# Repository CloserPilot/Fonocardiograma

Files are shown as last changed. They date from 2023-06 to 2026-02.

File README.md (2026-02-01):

# 🫀 Fonocardiograma

Sistema completo para **registro, visualización y análisis de fonocardiogramas (PCG)** que combina hardware electrónico, firmware para microcontrolador y aplicación móvil Android.
---

## 📌 Descripción del proyecto

Este proyecto entrega todas las partes necesarias para **reconstruir el dispositivo de prueba del fonocardiograma**, integrando adquisición de señal, transmisión inalámbrica y visualización multiplataforma.

Incluye:

- **Hardware** — diseños electrónicos y PCB para captura de señales acústicas cardiacas.
- **Firmware** — programa embebido para microcontrolador que adquiere y transmite datos.
- **Software móvil** — aplicación Android para comunicación con el hardware, visualización y exposición de datos en red local.
- **Documentación** — manuales y lista de partes.

Cada componente está diseñado para ser **independiente, reutilizable y extensible**.

---

## 📁 Estructura del repositorio

### 📦 APK/
Archivo **.apk instalable** de la aplicación Android, permitiendo su uso sin necesidad de compilación.

---

### 🛠 Circuitos/
Diseños electrónicos desarrollados en **KiCAD**:
- Esquemático del sistema.
- Diseño de PCB y capas correspondientes.

---

### 📲 Codigo AndroidStudio/
Proyecto completo de la aplicación Android desarrollado en **Android Studio**:
- Código fuente en Java.
- Interfaz de visualización de la señal.
- Gestión de conexión Bluetooth y red local.

La aplicación permite:
- Visualizar el fonocardiograma en el dispositivo móvil.
- Exponer la señal mediante **red local (LAN)** para su visualización en cualquier navegador web dentro de la misma red.

---

### 🧠 Codigo Arduino/
Código fuente para el microcontrolador (**ATTiny85 / AVR / Arduino compatible**):
- Configuración de ADC y adquisición de señal.
- Manejo de buffers de datos.
- Comunicación serial hacia el módulo Bluetooth **HC-05**.
- Scripts auxiliares para pruebas y depuración.

Este firmware es responsable de **capturar la señal acústica cardiaca y transmitirla a la aplicación móvil**.

---

### 📄 Documentacion.pdf
Documento técnico que describe:
- Objetivo del proyecto.
- Funcionamiento general del sistema.
- Interconexión entre hardware, firmware y aplicación.

---

### 🧾 Manual de usuario.pdf
Guía práctica para:
- Montaje del hardware.
- Uso del sistema de adquisición.
- Funcionamiento de la aplicación Android.
- Descripción de los módulos que integran la app.

---

### 📊 Lista de partes y costos.xlsx
Listado de componentes con:
- Cantidades requeridas.
- Costos estimados.
- Referencias de proveedores.

Facilita la reproducción del dispositivo.

---

## 📌 Uso del sistema

1. **Montaje de hardware**  
   Ensambla el circuito utilizando los esquemáticos de `Circuitos/` y la lista de partes.

2. **Carga de firmware**  
   Programa el microcontrolador con el código de `Codigo Arduino/`.

3. **Aplicación Android**  
   - Instala la app desde `APK/` o compílala desde `Codigo AndroidStudio/`.
   - Conecta el dispositivo vía Bluetooth.

4. **Visualización**  
   - Visualiza el fonocardiograma directamente en el teléfono.
   - Activa el **modo LAN** para acceder a la señal desde cualquier navegador web dentro de la misma red local (PC, tablet u otro dispositivo).

---

## 🎯 Casos de uso

- Prácticas académicas de bioinstrumentación.
- Análisis y estudio de bioseñales acústicas.
- Prototipado de sistemas biomédicos.
- Demostraciones de integración hardware–software–red.

---

## 🧩 Consideraciones

Este sistema **no sustituye equipos médicos certificados**. Está destinado a fines educativos, experimentales y de prototipado.

---

## 📜 Licencia

Licencia de código abierto (ver archivo `LICENSE` para detalles).

---

## 🤝 Contribuciones

Se aceptan mejoras en:
- Firmware
- Diseño electrónico
- Aplicación Android
- Visualización y análisis de señal

Usa *issues* o *pull requests* para proponer cambios.





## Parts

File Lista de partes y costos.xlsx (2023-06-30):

 | Fono_V3A | Fono_VB | Fono_VC
Componente | Cantidad | Cantidad | Cantidad | Cantidad Total | Detalles | Lote (Pz) | Lotes necesitados | Precio de Lote (Mx) | Placa A,B,C a fabricar | Total (Mx) | Link
R200K | 2 | 2 | 1 | 5 | Resistencia 0805 | 100 | 1 | 11 | 20.0 | 11.00 | https://es.aliexpress.com/item/1005001794062302.html?curPageLogUid=m6kVDcOp25Kb
R100K | 5 | 6 | 3 | 14 | Resistencia 0805 | 100 | 1 | 11 | 7.1 | 11.00
R75K | 1 | 1 | 2 | 4 | Resistencia 0805 | 100 | 1 | 11 | 25.0 | 11.00
R51K | 2 | 2 | 2 | 6 | Resistencia 0805 | 100 | 1 | 11 | 16.7 | 11.00
R39K | 1 |  |  | 1 | Resistencia 0805 | 100 | 1 | 11 | 100.0 | 11.00
R15K | 1 | 1 | 1 | 3 | Resistencia 0805 | 100 | 1 | 11 | 33.3 | 11.00
R10K | 5 | 3 | 3 | 11 | Resistencia 0805 | 100 | 1 | 11 | 9.1 | 11.00
R6.8K | 1 |  |  | 1 | Resistencia 0805 | 100 | 1 | 11 | 100.0 | 11.00
R5.1K |  | 1 |  | 1 | Resistencia 0805 | 100 | 1 | 11 | 100.0 | 11.00
R4.7K | 1 | 1 | 1 | 3 | Resistencia 0805 | 100 | 1 | 11 | 33.3 | 11.00
R1.2K | 1 | 1 | 1 | 3 | Resistencia 0805 | 100 | 1 | 11 | 33.3 | 11.00
R1K | 2 | 2 | 4 | 8 | Resistencia 0805 | 100 | 1 | 11 | 12.5 | 11.00
R51 | 2 | 2 | 1 | 5 | Resistencia 0805 | 100 | 1 | 11 | 20.0 | 11.00
Pot 100K | 2 | 1 | 1 | 4 | Potenciometro Rm065 | 20 | 1 | 17 | 5.0 | 17.00 | https://es.aliexpress.com/item/4000263405915.html
 |  |  |  |  |  |  |  |  | Total | 160.00 |  | Total Acumulado | 160.00
C2.2u | 4 | 4 | 4 | 12 | Condensador 0805 | 100 | 1 | 28 | 8.3 | 28.00 | https://es.aliexpress.com/item/32964553793.html
C1u |  |  | 2 | 2 | Condensador 0805 | 100 | 1 | 28 | 50.0 | 28.00
C470n | 6 | 6 | 4 | 16 | Condensador 0805 | 100 | 1 | 28 | 6.2 | 28.00
C100n | 3 | 3 | 7 | 13 | Condensador 0805 | 100 | 1 | 17 | 7.7 | 17.00
C22n | 1 | 2 | 1 | 4 | Condensador 0805 | 100 | 1 | 17 | 25.0 | 17.00
C3.3n | 1 |  |  | 1 | Condensador 0805 | 100 | 1 | 17 | 100.0 | 17.00
 |  |  |  |  |  |  |  |  | Total | 135.00 |  | Total Acumulado | 295.00
LED Verde | 1 | 1 | 1 | 3 | LED 0805 | 100 | 1 | 50 | 33.3 | 17 | https://es.aliexpress.com/item/1005002927878882.html
LED Amarillo | 1 | 1 | 1 | 3 | LED 0805 | 100 |  |  | 33.3
LED Rojo |  |  | 1 | 1 | LED 0805 | 100 |  |  | 100.0
1N5819WS |  |  | 1 | 1 | Diodo SOD-323 | 100 | 1 | 18 | 100.0 | 18.00 | https://es.aliexpress.com/item/4000331408283.html
 |  |  |  |  |  |  |  |  | Total | 35 |  | Total Acumulado | 330.00
78L05 | 1 | 1 |  | 2 | SOT-89 | 20 | 1 | 19 | 10.0 | 19.00 | https://es.aliexpress.com/item/1005003397363250.html
LP2985-5.0 |  |  | 1 | 1 | SOT-23 | 10 | 1 | 15 | 10.0 | 15.00 | https://es.aliexpress.com/item/32912924978.html?curPageLogUid=ZzuZ8RCBLQ2x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
LP2985-3.3 |  |  | 1 | 1 | SOT-23 | 10 | 1 | 17 | 10.0 | 17.00
LM324 | 2 | 2 | 2 | 6 | SOP-14 | 20 | 1 | 15 | 3.3 | 15.00 | https://es.aliexpress.com/item/32248693960.html
AD623 | 1 |  |  | 1 | SOP-8 | 2 | 1 | 73 | 2.0 | 73.00 | https://es.aliexpress.com/item/32837928321.html?curPageLogUid=gcZQZqIhE5QR
Attiny85 | 1 | 1 | 1 | 3 | SOP-8 | 1 | 3 | 63 | 1.0 | 189.00 | https://es.aliexpress.com/item/32953029405.html
Modulo HC-05 | 1 | 1 |  | 2 | Modulo | 1 | 2 | 45 | 1.0 | 90.00 | https://es.aliexpress.com/item/33003503284.html
HC-05 no welding |  |  | 1 | 1 | HC-05 | 1 | 1 | 41 | 1.0 | 41.00
Microfono Electret | 1 | 1 | 1 | 3 | CMC-6015-42P | 1 | 3 | 50 | 1.0 | 150.00 | https://www.mouser.mx/ProductDetail/CUI-Devices/CMC-6015-42P?qs=48I1WSKJTyZ1WFntk70QQA%3D%3D
MAX9814 |  | 1 | 1 | 2 | Modulo | 1 | 2 | 38 | 1.0 | 76.00 | https://es.aliexpress.com/item/1005003788312771.html
 |  |  |  |  |  |  |  |  | Total | 685.00 |  | Total Acumulado | 1015.00
Switch | 1 | 1 | 1 | 3 | SS12D00 | 100 | 1 | 28 | 33.3 | 28.00 | https://es.aliexpress.com/item/32721440534.html
Button |  |  | 1 | 1 | 3x4x2H | 100 | 1 | 19 | 100.0 | 19.00 | https://es.aliexpress.com/item/1005004601389175.html?curPageLogUid=IotoW6NB7fPm
PinHeader | 17 | 20 | 16 | 53 | Pin header 2.54mm | 400 | 1 | 20 | 7.5 | 20.00 | https://es.aliexpress.com/item/1005003541838313.html?curPageLogUid=lTdUJPTQU6WD
Jumper | 8 | 9 | 7 | 24 | Jumper 2.54mm | 100 | 1 | 30 | 4.2 | 30.00 | https://es.aliexpress.com/item/1005001470793144.html?curPageLogUid=JM6QI5mDvHdO
JST M/H | 2 | 2 | 2 | 6 | JST | 50 | 1 | 10 | 8.3 | 10.00 | https://es.aliexpress.com/item/4000029712674.html
Conector 9V | 1 | 1 | 1 | 3 | Conector de bateria 9V | 20 | 1 | 34 | 6.7 | 34.00 | https://es.aliexpress.com/item/32828062495.html
Pila 9V | 1 | 1 | 1 | 3 | Pila de 9V | 1 | 3 | 35 | 1.0 | 105.00 | https://articulo.mercadolibre.com.mx/MLM-856527302-pila-de-carbon-9v-bateria-cuadrada-_JM
 |  |  |  |  |  |  |  |  | Total | 246.00 |  | Total Acumulado | 1261.00
Pulsera antiestatica | 1 | 1 | 1 | 3 | Pulsera antiestaica | 1 | 3 | 56 | 1.0 | 168.00 | https://es.aliexpress.com/item/1005004420555312.html?curPageLogUid=hVagJRj90b4p
Estetoscopio | 1 | 1 | 1 | 3 | Estetocopio (campana) | 1 | 3 | 70 | 1.0 | 210.00 | https://es.aliexpress.com/item/32982796216.html?scm_id=1007.33416.274820.0&scm-url=1007.33416.274820.0
 |  |  |  |  |  |  |  |  | Total | 378.00 |  | Total Acumulado | 1639.00
Creación de placas | 1 | 1 | 1 | 3 | Creacion de placas | 10 de cada uno | 1 | 100 |  | 300 | https://www.pcbway.com/ | Total Acumulado | 1939.00
Envio Aliexpress |  |  |  |  | Total de costo de envio |  |  |  |  | 405
Envio Mouser |  |  |  |  | Total de costo de envio |  |  |  |  | 550
Envio PCBWAY |  |  |  |  | Total de costo de envio |  |  |  |  | 550
Envio mercado libre |  |  |  |  | Total de costo de envio |  |  |  |  | 89
 |  |  |  |  |  |  |  |  | Total | 1594
 |  |  |  |  |  |  |  |  | Total | 3533.00

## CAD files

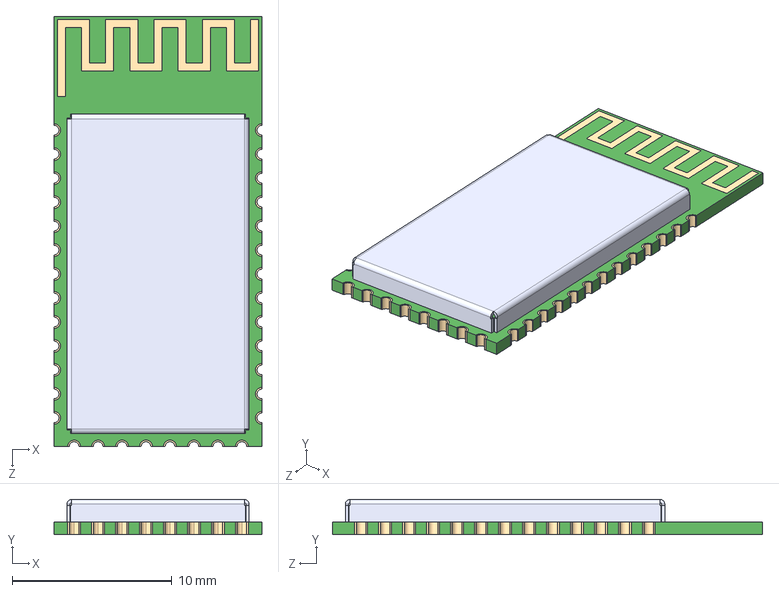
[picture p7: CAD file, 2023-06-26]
Circuitos/Acondicionamiento_V3C/HC-05.step
13.0 x 2.20 x 26.9 mm

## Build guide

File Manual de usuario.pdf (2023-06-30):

# Desarrollo de un fonocardiógrafo portátil inalámbrico conectado a dispositivos dentro de la red local y dispositivos móviles

# Manual de usuario

Nota: Dentro del repositorio https://github.com/CloserPilot/Fonocardiograma, se encuentra toda la información del prototipo (diagramas y código fuente).

# 1 Circuito electrónico

Teniendo el circuito ensamblado, se pueden distinguir 3 conexiones principales (Figura 1)

- De color rojo: Se encuentra la entrada a la fuente de alimentación, en este conector se conecta la batería de 9V.
- De color azul: Se encuentra la tierra virtual hacia el paciente, en esta terminal se conecta la pulsera antiestática (en caso de requerirlo).
- De color amarillo: Se encuentra el control de ganancia, con ayuda de un desarmador plano es posible controlar la ganancia del circuito

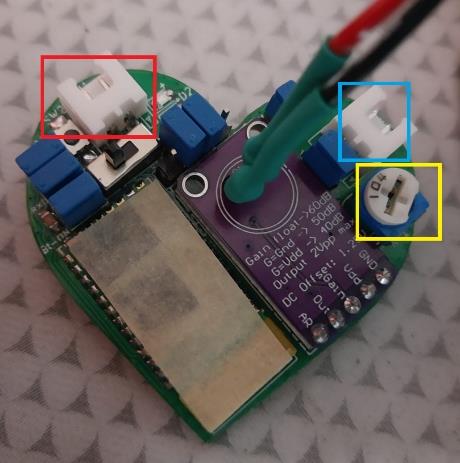
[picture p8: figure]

Figura 1.- Circuito ensamblado del fonocardiograma

Al estar conectado se tienen 3 indicadores led:

- Indicador de encendido: Led verde encontrado en los tres módulos. Al energizar el circuito, este led se enciende.
- Indicador de emparejamiento bluetooth: Siendo de color rojo para la placa del “Módulo A” y “Módulo B” y de color amarillo para el “Módulo C. Al parpadear de manera repentina indicad que el dispositivo está desconectado, al tener parpadeos con un mayor intervalo de tiempo, indica que el dispositivo está emparejado.
- Indicador de batería baja: Siendo de color amarillo en el “Módulo A” y “Módulo B” y de color rojo en el “Módulo C”. Al estar encendido este led, indica que es necesario cambiar la batería debido a su nivel bajo de voltaje.

# 2 Aplicación Android

Dentro del repositorio https://github.com/CloserPilot/Fonocardiograma, se encuentra una carpeta llamada “APK”, dentro de esta carpeta se encuentra la versión ejecutable de la aplicación, basta con descargarla en el celular e instalarla.

# 2.1 Funcionamiento de la aplicación móvil 2.1.1 Sincronización del circuito del

fonocardiograma.

Siendo la primera vez que se usa la aplicación móvil con el circuito del fonocardiograma, es necesario emparejar el circuito con el celular. Para ello se va a “Opciones Bluetooth” y se trata de emparejar un nuevo dispositivo, según la configuración de la placa debería aparecer de la siguiente manera (Figura 2):

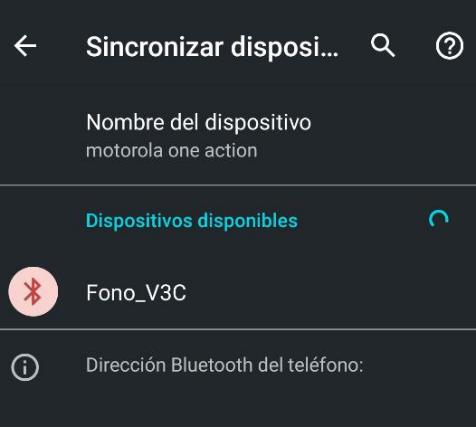
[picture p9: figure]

Figura 2.- Vinculación del dispositivo por primera vez

Una vez vinculado el dispositivo, se abre la aplicación del celular (Figura 3):

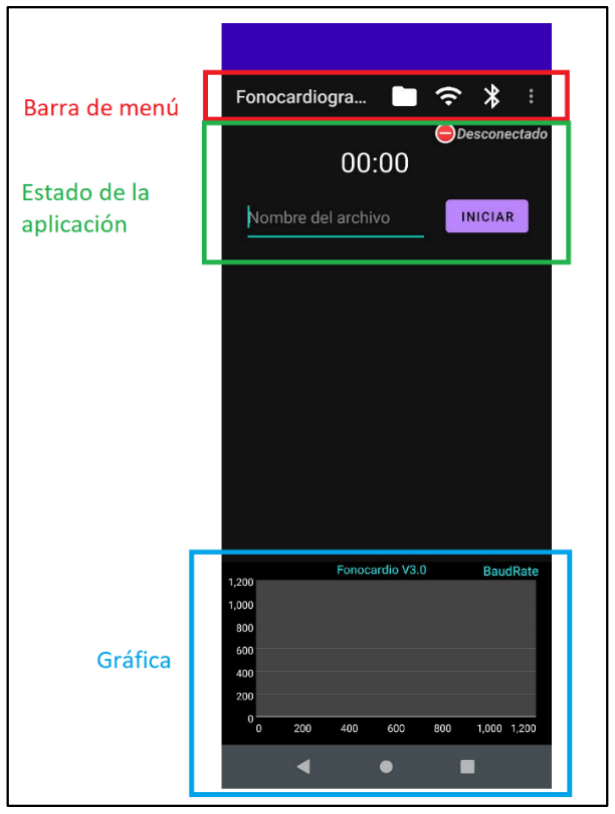
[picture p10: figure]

Figura 3.- Secciones de la aplicación móvil.

Inicialmente, la aplicación se encuentra desconectada del circuito del fonocardiograma, para conectarlo es necesario dar clic dentro de la sección de “Barra de menú” en el ícono Bluetooth.

Al dar clic, se abre la siguiente ventana (Figura 4):

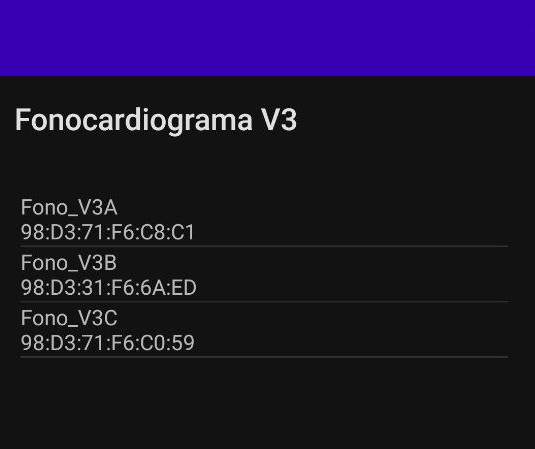
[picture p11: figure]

Figura 4.- Opciones de emparejamiento bluetooth

Para conectarse, es necesario seleccionar el dispositivo del fonocardiograma y esperar que la conexión quede establecida.

Nota: En caso de no ver el dispositivo del fonocardiograma, se debe de tratar de volver a emparejar el celular con el circuito del fonocardiograma.

En caso de haber una conexión exitosa, el ícono de estado parpadeará de color verde y el letrero cambiará a “Conectado” (Figura 5).

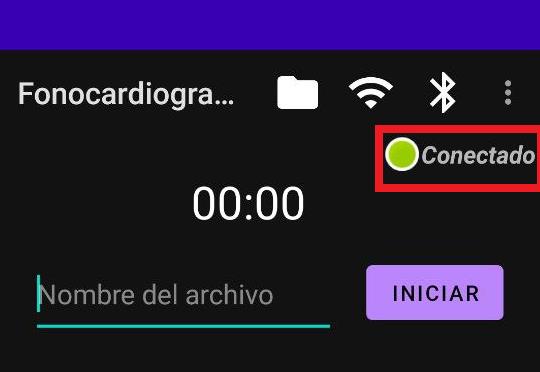
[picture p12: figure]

Figura 5.- Conexión bluetooth exitosa.

En caso de haber algún problema con la conexión bluetooth, aparecerá el siguiente cuadro de diálogo (Figura 6):

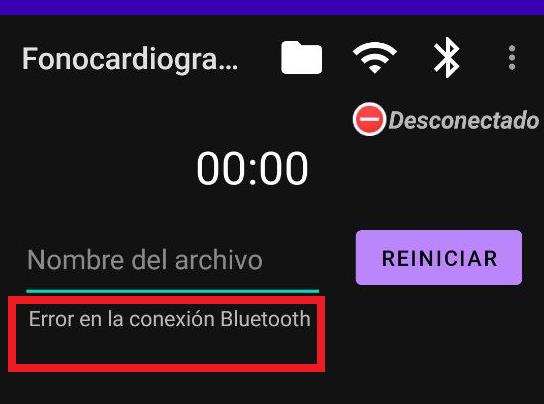
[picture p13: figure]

Figura 6.- Error en la conexión bluetooth.

# 2.1.2 Creación del archivo

Una vez vinculado el celular con el circuito del fonocardiograma, el siguiente paso es nombrar al archivo. En el cuadro de dialogo de la Figura 7, se agrega el nombre que tendrá el archivo.

Nota: Si existe un archivo con el mismo nombre, este será SOBREESCRITO.

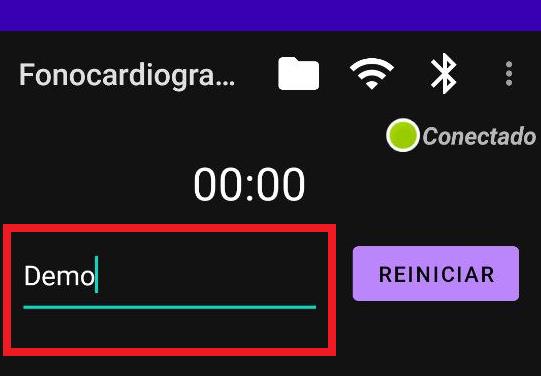
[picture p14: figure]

Figura 7.- Insertar el nombre del archivo

En caso de haber un error al tratar de crear el archivo, se mostrará un texto en la parte inferior del nombre del archivo (Figura 8)

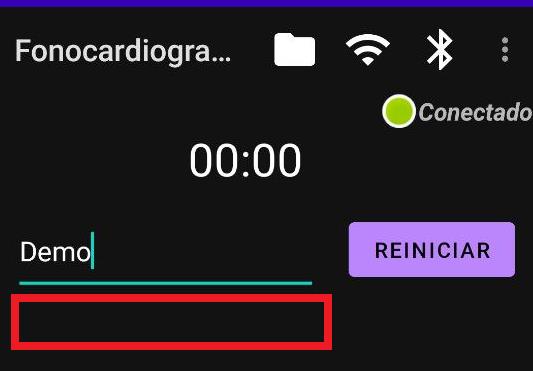
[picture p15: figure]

Figura 8.- Ubicación del cuadro de error en la creación del archivo.

Para conocer la ruta donde será almacenado el archivo, se da clic en el ícono en forma de carpeta, de esta forma aparecerá la ruta del archivo debajo de su nombre (Figura 9).

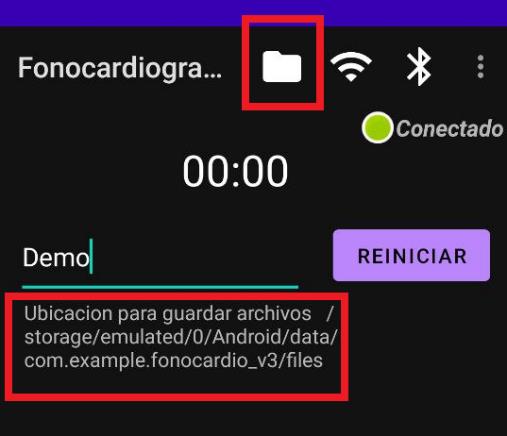
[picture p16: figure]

Figura 9.- Ruta para guardar el archivo.

# 2.1.3 Muestreo de la señal

Una vez vinculado el bluetooth y elegido el nombre del archivo, se da clic en el botón ”Iniciar/Reiniciar”, con esto se manda la señal de inicio del muestreo al circuito físico y se empieza a captura la información.

Al iniciar, el cronómetro empezará a correr y el botón de “Iniciar/Reiniciar”, cambiará a “Detener” . De igual forma, en la parte inferior de la aplicación se empezarán a graficar los datos del fonocardiograma (Figura 10).

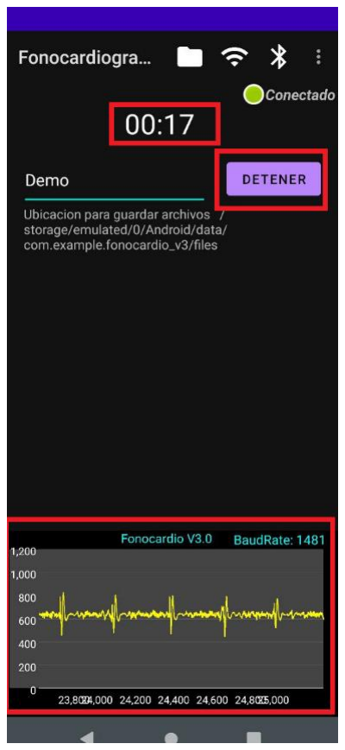
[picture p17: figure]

Figura 10.- Muestreo de la señal.

Para detener el muestreo, basta con dar clic en el botón de “Detener”. Al detener la cuenta, la información es guardada en el archivo creado y se espera la instrucción para “Reiniciar”.

Nota: Al parar la cuenta y volverla a correr, se trata de una nueva instancia, es decir, LOS NUEVOS DATOS SOBRESCRIBIRÁN A LOS VIEJOS. La opción de “Detener” está pensada para cerrar los datos del paciente actual y esperar los datos de uno DIFERENTE al dar clic en “Reiniciar”.

# 2.1.4 Configuración

Es posible configurar algunas funciones de la aplicación. Para acceder a la configuración basta con dar clic en los tres puntos del lado superior derecho y en “Configuración” (Figura 11).

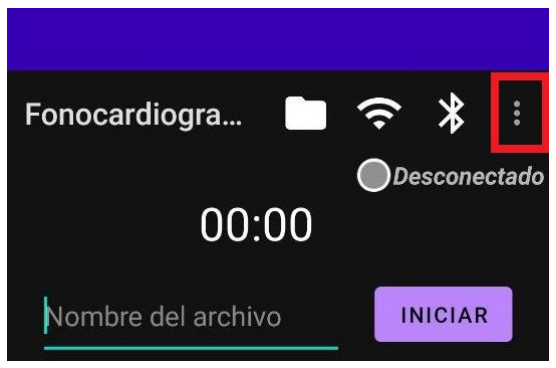
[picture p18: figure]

Figura 11.- Más opciones, configuración.

Al dar clic, se abre la siguiente ventana emergente (Figura 12):

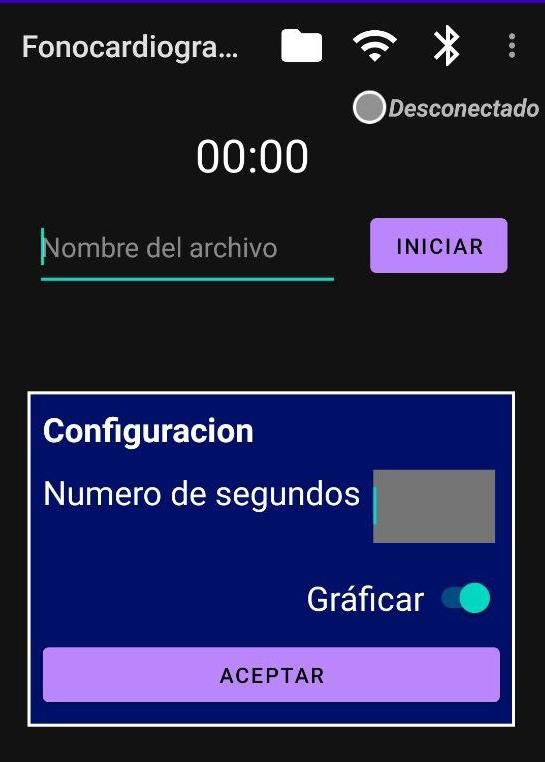
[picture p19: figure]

Figura 12.- Configuración.

Dentro de esta ventana, es posible cambiar el número de segundos a mostrar en la gráfica, así como habilitar o deshabilitar la gráfica del celular. Una vez configuradas las opciones se da clic en “Aceptar” para aplicar los cambios.

Nota: La opción de “Graficar” fue implementada debido a que la aplicación móvil presenta problemas de rendimiento con respecto a la gráfica, una mejor versión de la gráfica puede ser vista a través del navegador dentro de la red local.

# 2.1.5 Red local

Para acceder a la aplicación dentro de la red local es necesario saber la IP del celular, para esto se da clic en el ícono wifi de la barra de menú. La dirección IP será desplegada debajo del nombre del archivo (Figura 13).

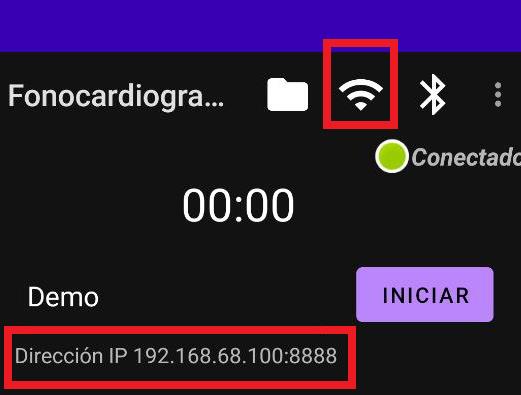
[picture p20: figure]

Figura 13.- Dirección IP del dispositivo.

# 2.2 Funcionamiento de la aplicación en red local

Para acceder a la aplicación dentro de la red local es necesario seguir los pasos de la sección 2.1 Funcionamiento de la aplicación móvil. Una vez configurada la conexión bluetooth, el nombre del archivo y la dirección IP del dispositivo, se abre cualquier navegador DENTRO DE LA RED LOCAL, y se escribe la IP junto con el puerto mostrado en la aplicación (por ejemplo 192.168.68.100:8888).

Al tener una conexión exitosa, se muestra la siguiente pantalla (Figura 14):

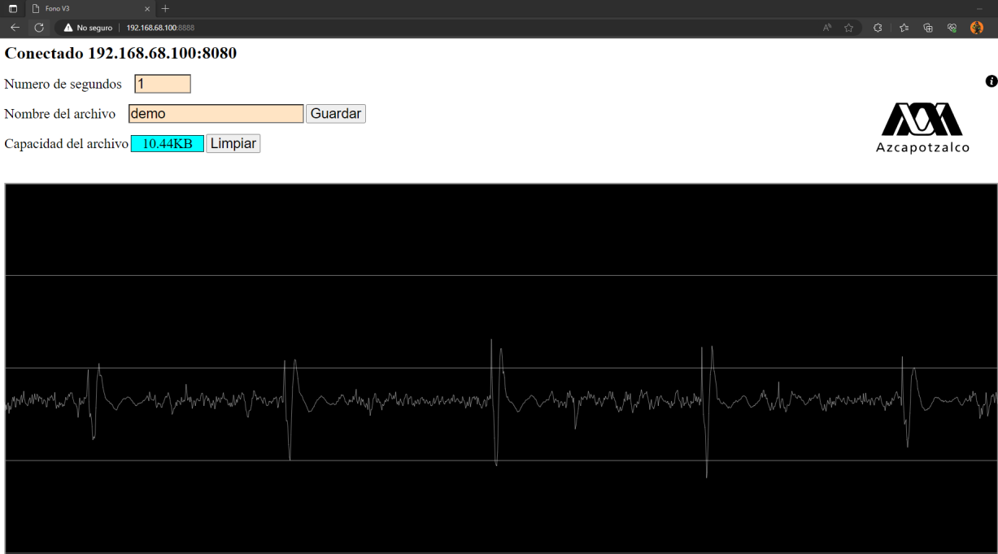
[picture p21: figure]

Figura 14.- Aplicación de la red local.

Nota: La gráfica de color negro, aparece únicamente si el muestreo se ha iniciado, caso contrario, al conectarse por primera vez sin datos recibidos, la gráfica no aparecerá, ésta aparece automáticamente una vez que inicie el muestreo.

Nota: En caso de que la página tarde mucho en cargar, se recomienda actualizarla desde el navegador la veces que sea necesario. A veces el WebSocket presenta problemas de conexión y es necesario actualizarlo manualmente.

# 2.2.1 Muestreo de la señal

La aplicación en red local graficará de manera automática los datos mandados por el teléfono, si el teléfono no recibe datos del circuito del fonocardiograma, el navegador no tendrá datos para actualizar. El teléfono funciona como controlador para iniciar y detener el ingreso de datos en el navegador.

# 2.2.2 Configuración

En la parte superior del navegador se encuentra una sección para configurar algunos parámetros de la aplicación:

- Número de segundos: Se elije cuantos segundos se quiere mostrar en la gráfica del navegador (de manera similar que, en el celular, sección 2.1.4 Configuración)
- Nombre del archivo: Se elije un nombre para el archivo a descarga con la información actual.
- Limpiar: El funcionamiento de este botón es el de borrar toda la información guarda hasta el momento.

# 2.2.3 Creación del archivo

De manera similar a la aplicación en el celular, es posible crear un archivo con toda la información recibida hasta el momento y descargarlo desde el navegador hacia el dispositivo conectado en la red local. Para ello existe un cuadro de dialogo que permite cambiar el nombre del archivo (Figura 15). Una vez cambiado, se da clic en el botón de “Guardar” y comienza la descarga del archivo.

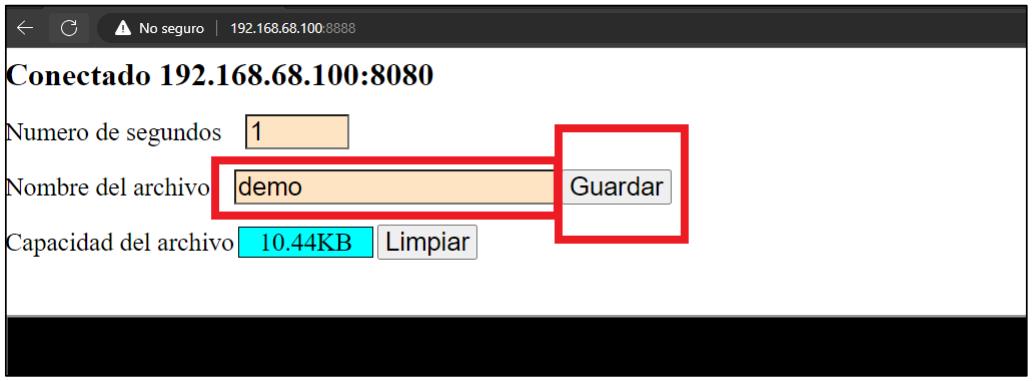
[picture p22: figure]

Figura 15.- Nombre del archivo a descargar.

Para borrar toda la información guardada hasta el momento y poder generar un archivo nuevo, se da clic en el botón “Limpiar”. El tamaño aproximado del archivo puede verse en el recuadro de color azul (Figura 16).

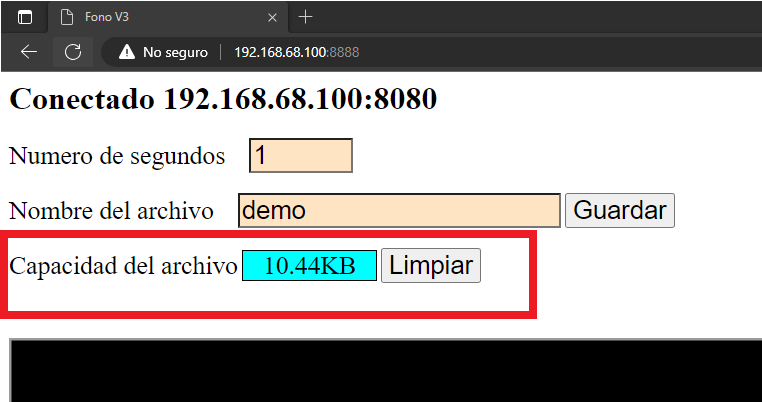
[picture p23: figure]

Figura 16.- Limpiar

# 2.3 Partes de la aplicación móvil

La pantalla principal de la aplicación móvil puede ser dividida en las siguientes secciones (Figura 17):

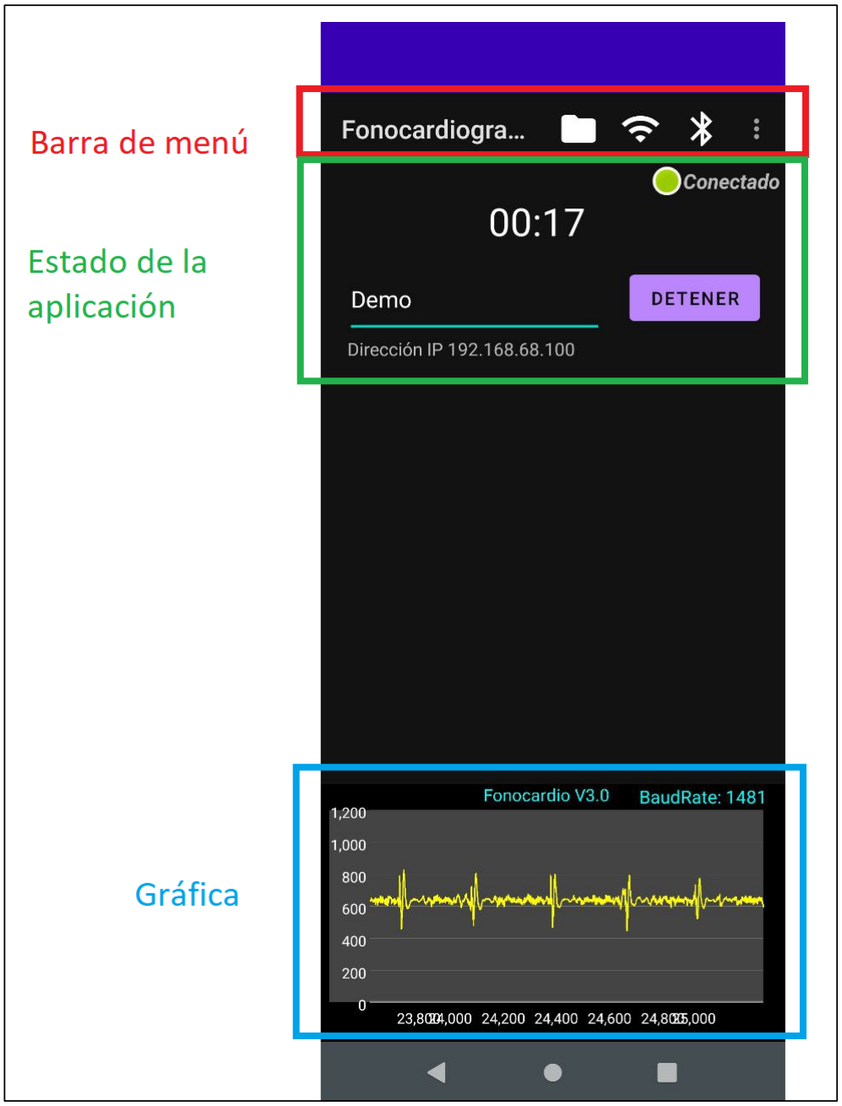
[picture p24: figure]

Figura 17.- Secciones de la aplicación móvil.

# 2.3.1 Barra de menú

Dentro de esta barra se encuentran los siguientes íconos (Figura 18) :

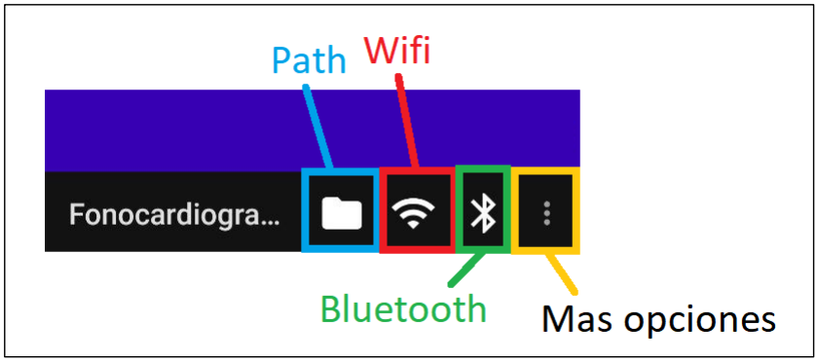
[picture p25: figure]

Figura 18.- Barra de menú.

- Path: Botón para mostrar el directorio donde se guardará el archivo con la información recopilada del fonocardiograma.
- Wifi: Botón para mostrar la dirección IP del celular, esta dirección será usada para conectarse a través del navegador al celular dentro de la red local.
- Bluetooth: Botón para seleccionar el dispositivo a conectar (circuito del fonocardiograma) con la aplicación del celular.
- Mas opciones: Al presionar el botón, aparecen dos opciones más (Figura 19):
- Configuración: Menú desplegable para configurar ciertos parámetros de la aplicación
- Información: Información sobre la aplicación.

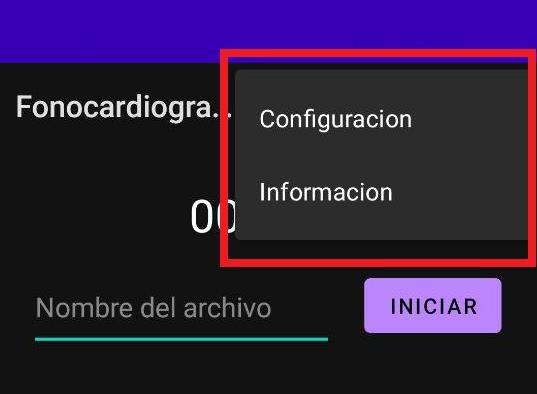
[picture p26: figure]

Figura 19.- Mas opciones

Al dar clic en “Configuración” se abre la siguiente ventana (Figura 20). Dentro de esta ventana se encuentra la opción de “Numero de segundos” el cual permite modificar el número de segundos a visualizar en la gráfica del celular. Otra opción es la de habilitar o deshabilitar la gráfica.

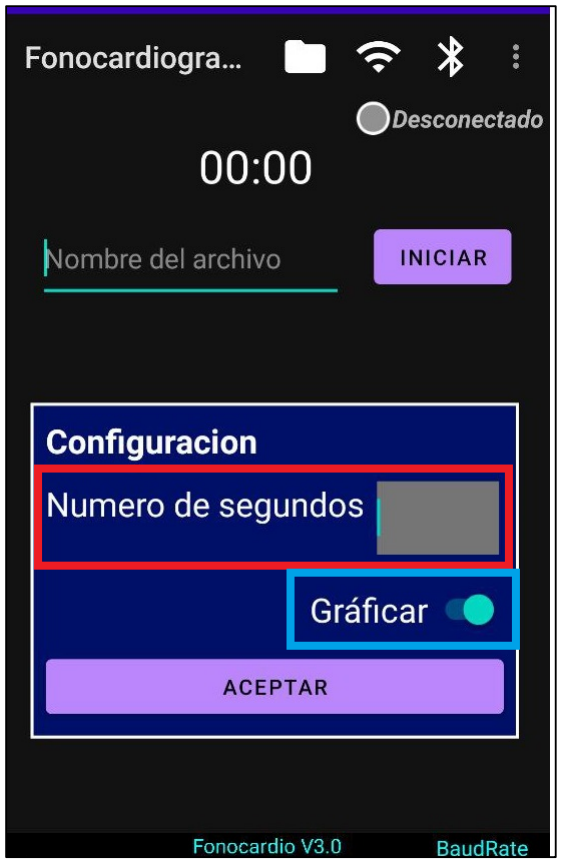
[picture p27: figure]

Figura 20.- Configuración, aplicación móvil.

Por último, la opción “Información” del menú desplegable, muestra un mensaje con la información de la aplicación (Figura 21).

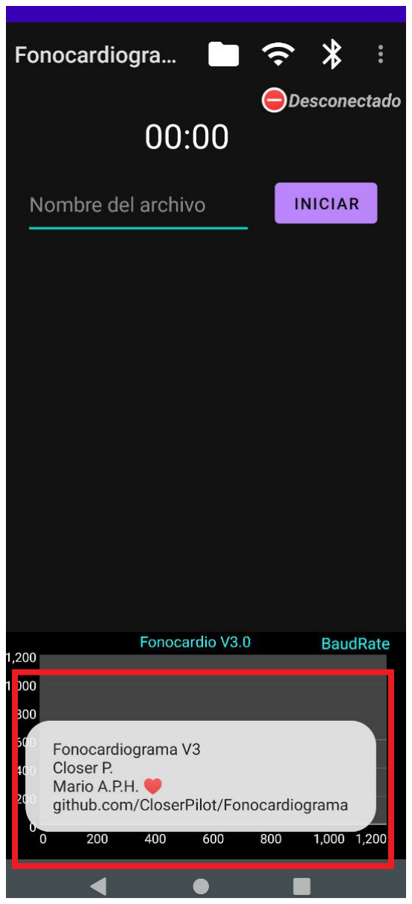
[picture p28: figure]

Figura 21.- Información, aplicación móvil.

# 2.3.2 Estado de la aplicación

Dentro de esta sección se encuentran los siguientes elementos (Figura 22):

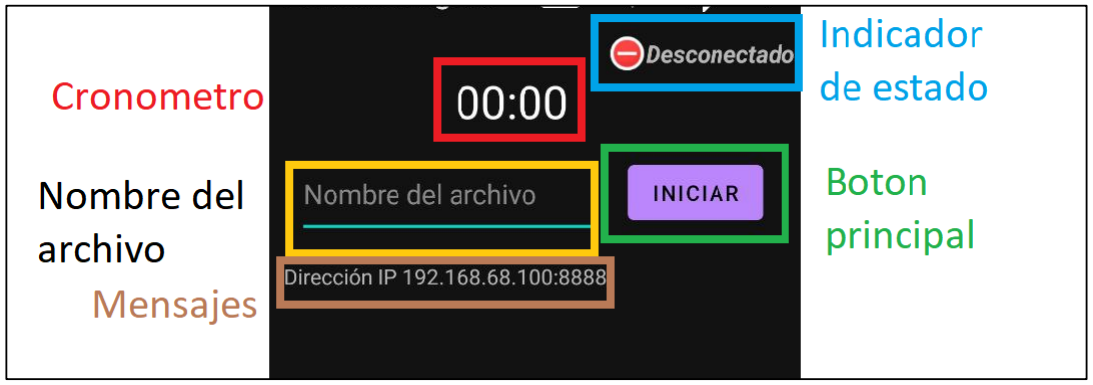
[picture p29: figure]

Figura 22.- Estado de la aplicación.

- Indicador de estado: Este ícono indica el estado actual del bluetooth, en caso de que la conexión se exitosa, el ícono parpadeará de color verde junto con el mensaje “Conectado”, en caso contrario, el ícono parpadeará de color rojo con la leyenda “Desconectado”.
- Botón principal: Botón de control para el muestreo de la aplicación. Este botón es el que controla el inicio y final del muestreo.
- Cronómetro: Indicador del tiempo total de muestreo.
- Nombre del archivo: Entrada para el nombre del archivo de los datos a guardar.
- Mensaje: Mensajes importantes a comunicar con el usuario.

# 2.3.3 Gráfica

Dentro de esta sección se distinguen dos elementos principales (Figura 23):

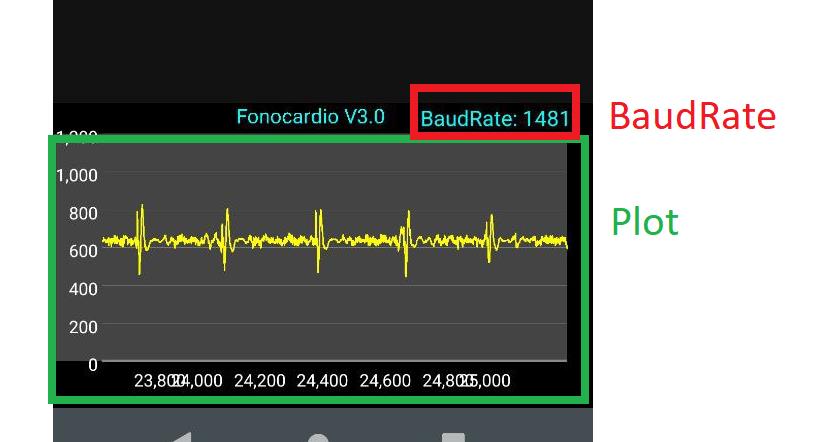
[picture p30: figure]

Figura 23.- Gráfica, aplicación móvil.

- Plot: Gráfica con los datos en tiempo real del fonocardiograma.
- BaudRate: Velocidad de muestreo de los datos.

# 2.4 Partes de la aplicación en red local

La aplicación en red local puede ser dividida en las siguientes partes (Figura 24):

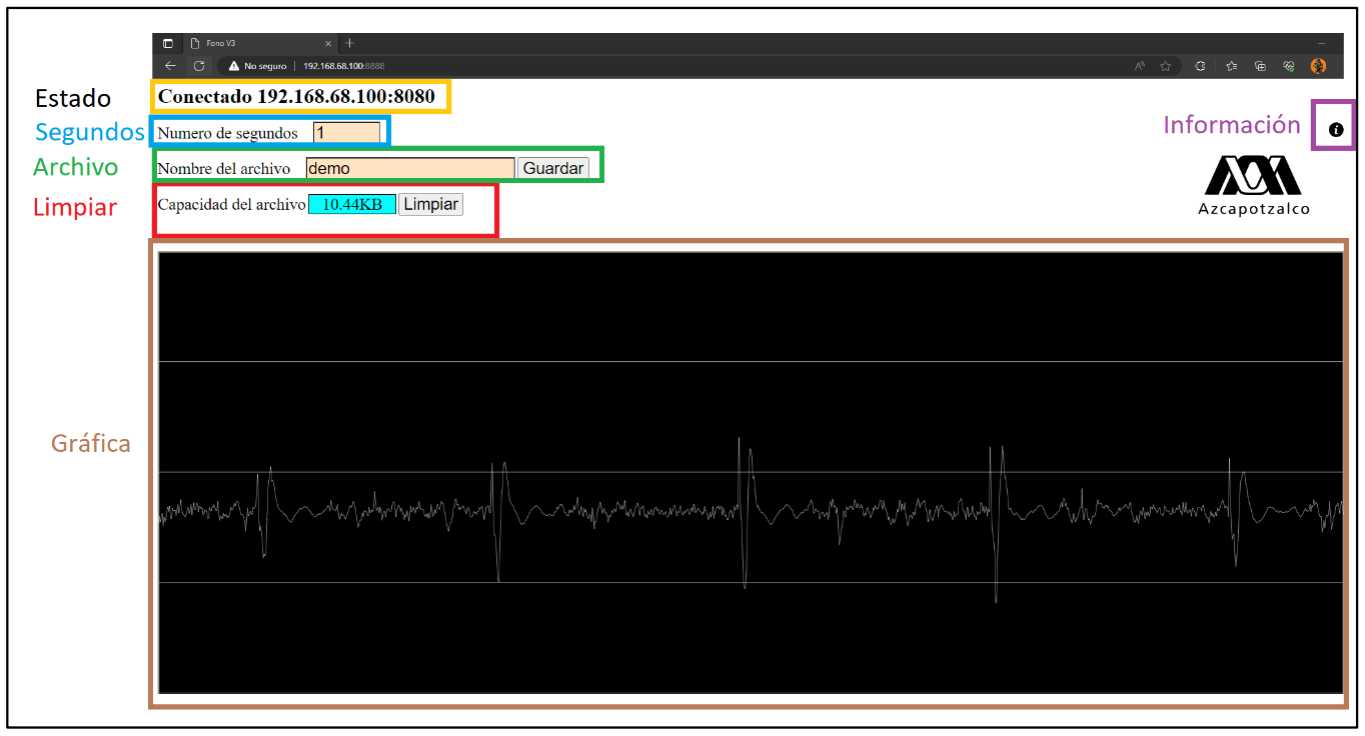
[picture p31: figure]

Figura 24.- Partes de la aplicación en red local.

- Estado: Muestra el estado actual de la aplicación en red local.
- Segundos: Variable para controlar el número de segundos a mostrar en la gráfica.
- Archivo: Nombre del archivo para descargar los datos desde el navegador.
- Limpiar: En caso de requerirlo, se pueden limpiar todos los datos almacenados hasta el momento y comenzar a guardar datos nuevos.
- Gráfica: Gráfica de los datos en tiempo real enviados desde el celular.
- Información: Abre una ventana emergente con información sobre la aplicación.

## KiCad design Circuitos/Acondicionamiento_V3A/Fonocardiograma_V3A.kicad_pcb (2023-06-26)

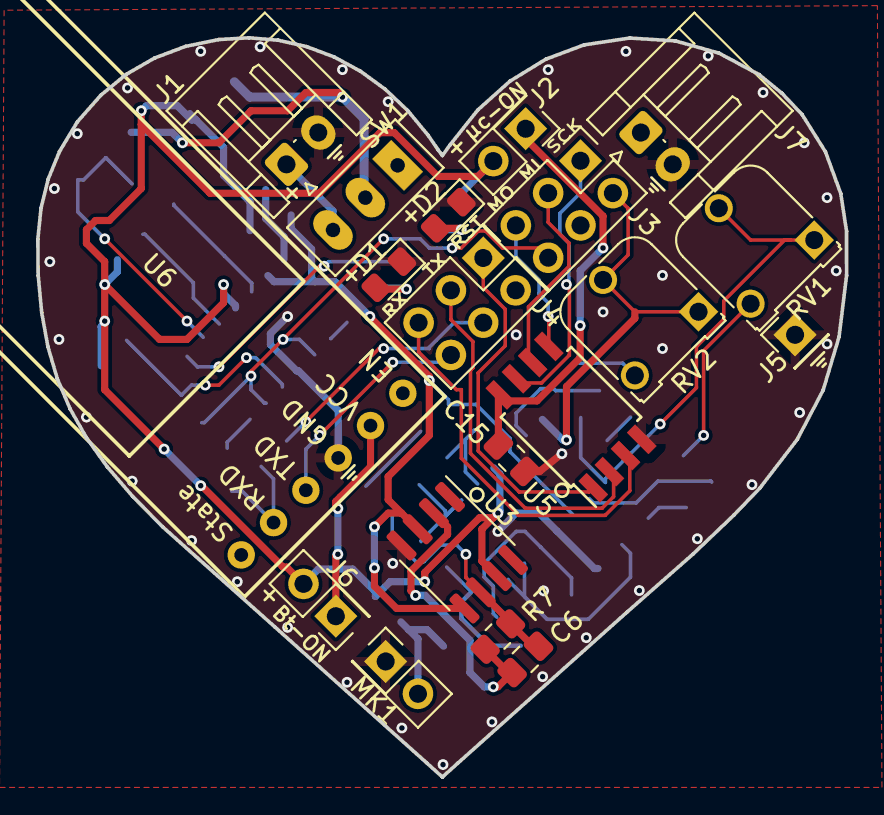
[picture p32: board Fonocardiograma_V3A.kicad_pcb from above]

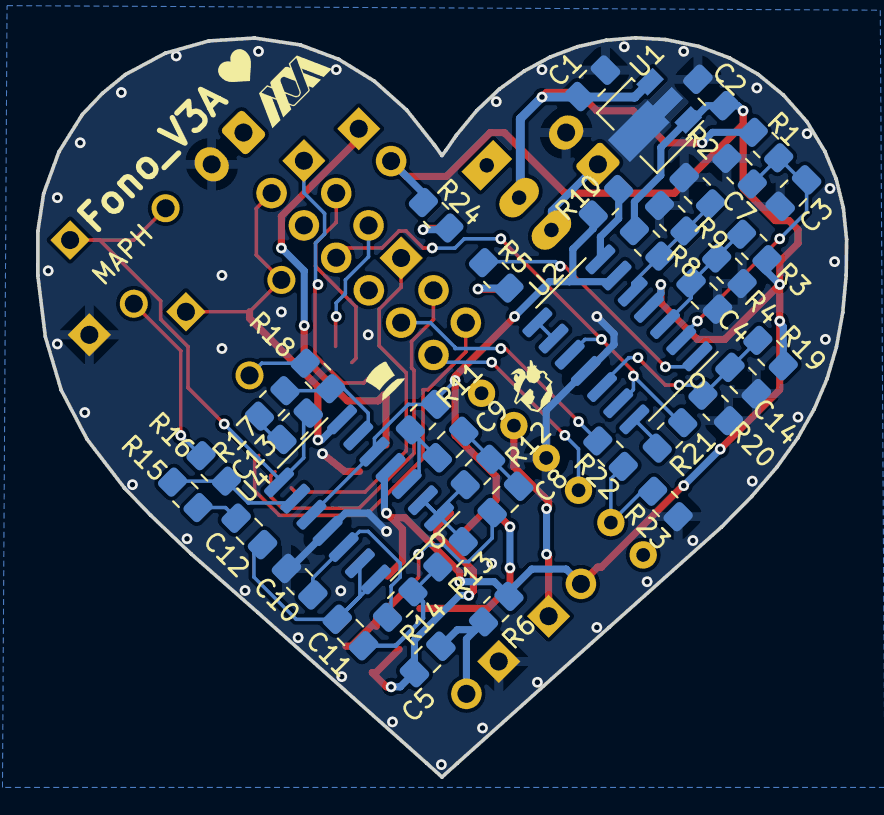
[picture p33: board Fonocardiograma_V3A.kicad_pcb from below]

Board: 2 copper layers, 44.9 x 41.1 mm, 58 parts (39 on the bottom side), 44 nets.

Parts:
C1: 330nf; C_0805_2012Metric_Pad1.18x1.45mm_HandSolder
C2: 100nf; C_0805_2012Metric_Pad1.18x1.45mm_HandSolder
C3, C4, C7, C9, C14, C15: 470n; C_0805_2012Metric_Pad1.18x1.45mm_HandSolder
C5, C8, C12, C13: 2.2u; C_0805_2012Metric_Pad1.18x1.45mm_HandSolder
C6: 3.3n; C_0805_2012Metric_Pad1.18x1.45mm_HandSolder
C10: 22n; C_0805_2012Metric_Pad1.18x1.45mm_HandSolder
C11: 100n; C_0805_2012Metric_Pad1.18x1.45mm_HandSolder
D1, D2: LED; LED_0805_2012Metric_Pad1.15x1.40mm_HandSolder
J1, J7: Conn_01x02; JST_EH_S2B-EH_1x02_P2.50mm_Horizontal
J2, J6: Conn_02x01; PinHeader_2x01_P2.54mm_Vertical
J3, J4: Conn_02x03_Odd_Even; PinHeader_2x03_P2.54mm_Vertical
J5: Conn_01x01; PinHeader_1x01_P2.54mm_Vertical
MK1: Microphone_Condenser; PinHeader_2x01_P2.54mm_Vertical
R1, R3, R4: 100K; R_0805_2012Metric_Pad1.20x1.40mm_HandSolder
R2: 51K; R_0805_2012Metric_Pad1.20x1.40mm_HandSolder
R5, R24: 330; R_0805_2012Metric_Pad1.20x1.40mm_HandSolder
R6: 6.8k; R_0805_2012Metric_Pad1.20x1.40mm_HandSolder
R7: 39k; R_0805_2012Metric_Pad1.20x1.40mm_HandSolder
R8: 75k; R_0805_2012Metric_Pad1.20x1.40mm_HandSolder
R9: 51k; R_0805_2012Metric_Pad1.20x1.40mm_HandSolder
R10, R21: 50; R_0805_2012Metric_Pad1.20x1.40mm_HandSolder
R11: 15k; R_0805_2012Metric_Pad1.20x1.40mm_HandSolder
R12: 4.7k; R_0805_2012Metric_Pad1.20x1.40mm_HandSolder
R13: 1.2k; R_0805_2012Metric_Pad1.20x1.40mm_HandSolder
R14, R15, R16, R17, R18: 10k; R_0805_2012Metric_Pad1.20x1.40mm_HandSolder
R19, R22: 100k; R_0805_2012Metric_Pad1.20x1.40mm_HandSolder
R20, R23: 200k; R_0805_2012Metric_Pad1.20x1.40mm_HandSolder
RV1, RV2: 100k; Potentiometer_Runtron_RM-065_Vertical
SW1: SW_SPDT; SW_Slide_1P2T_SS12D00G4
U1: L78L05_SOT89; SOT-89-3
U2, U4: LM324; SOIC-14_3.9x8.7mm_P1.27mm
U3: AD623; SOIC-8_3.9x4.9mm_P1.27mm
U5: ATtiny85-20S; SOIC-8W_5.3x5.3mm_P1.27mm
U6: HC-05

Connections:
2V Vref: R10.2, R11.2, U2.6 (-), U3.3 (+), U3.5 (Ref), U4.5 (+), U4.10 (+)
+5V: C2.1, J2.2, J6.2, R3.2, R6.2, R8.2, R19.2, R24.2, U1.1 (OUT), U2.4 (V+), U3.7 (Vs+), U4.4 (V+)
+9V: C1.1, R1.2, SW1.2 (B), U1.3 (IN)
ADC1: J3.2, RV2.1, RV2.2, U4.7
AREF: J3.6, R21.2, U2.10 (+), U2.13 (-)
GND: C1.2, C2.2, C3.1, C4.1, C7.1, C10.1, C14.1, C15.1, D1.1 (K), D2.1 (K), J1.2, J5.1, J7.2, MK1.1 (-), R2.1, R4.1, R9.1, R20.1, R23.2, U1.2 (GND), U2.11 (V-), U3.4 (Vs-), U4.11 (V-), U5.4 (GND), U6.4 (GND)
MISO: J3.3, U5.6 (PB1)
MOSI/AREF: J3.5, U5.5 (AREF/PB0)
unnamed: C6.2, C8.2, R7.1, U3.6
unnamed: C8.1, C9.1, R12.1
unnamed: C11.1, R13.2, R14.1
unnamed: C12.1, R15.2
unnamed: C13.1, R17.2
unnamed: C13.2, RV1.1, RV1.2, U4.8
unnamed: D1.2 (A), R5.2
unnamed: D2.2 (A), R24.1
unnamed: J1.1, SW1.3 (C)
unnamed: C15.2, J2.1, U5.8 (VCC)
unnamed: J6.1, U6.5 (VCC)
unnamed: C5.1, MK1.2 (+), R6.1
unnamed: R5.1, U2.1
unnamed: R10.1, U2.7
unnamed: R16.1, RV1.3
unnamed: R18.1, RV2.3
unnamed: R21.1, U2.14
unnamed: C4.2, R3.1, R4.2, U2.3 (+)
unnamed: C3.2, R1.1, R2.2, U2.2 (-)
unnamed: C7.2, R8.1, R9.2, U2.5 (+)
unnamed: U2.8, U2.9 (-)
unnamed: C14.2, R19.1, R20.2, U2.12 (+)
unnamed: C5.2, C6.1, R7.2, U3.2 (-)
unnamed: C9.2, R11.1, U4.3 (+)
unnamed: R12.2, R13.1, U4.1, U4.2 (-)
unnamed: R17.1, R18.2, U4.6 (-)
unnamed: R15.1, R16.2, U4.9 (-)
unnamed: C10.2, R14.2, U4.12 (+)
unnamed: C11.2, C12.2, U4.13 (-), U4.14
unnamed: R22.2, R23.1, U6.2 (RXD)
RESET: J4.1, U5.1 (~RESET/PB5)
RX: J4.5, U5.3 (XTAL2/PB4)
RXD: J4.4, R22.1
SCK/ADC1: J3.1, U5.7 (PB2)
TX: J4.3, U5.2 (XTAL1/PB3)
TXD: J4.6, U6.3 (TXD)

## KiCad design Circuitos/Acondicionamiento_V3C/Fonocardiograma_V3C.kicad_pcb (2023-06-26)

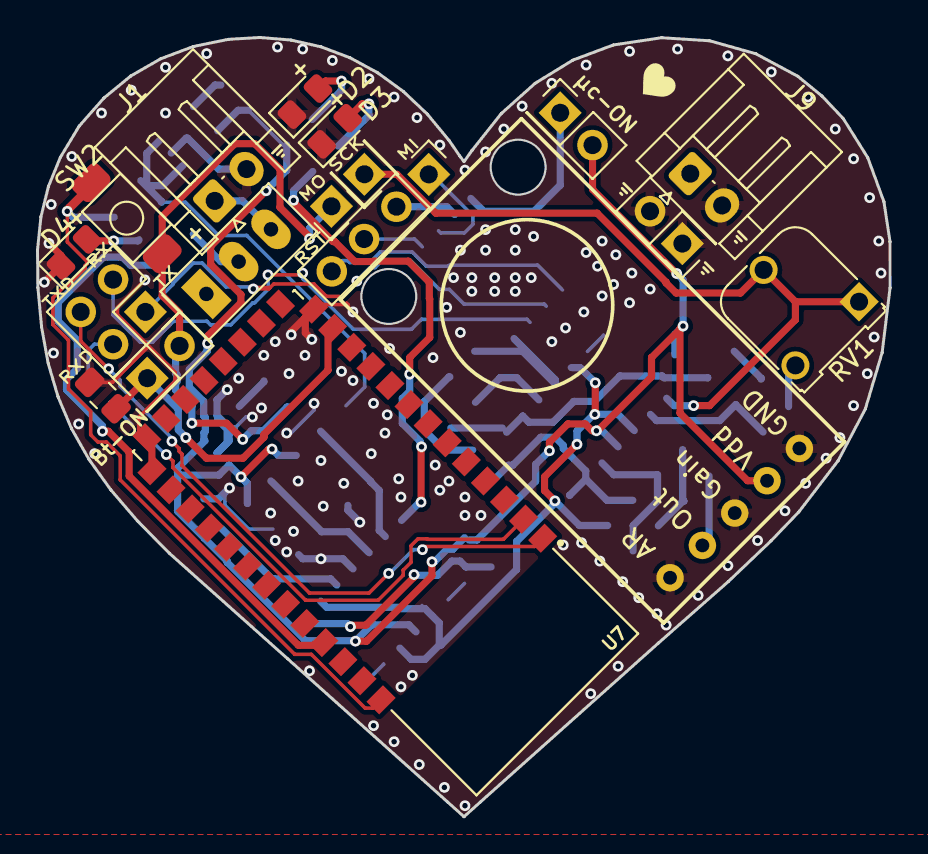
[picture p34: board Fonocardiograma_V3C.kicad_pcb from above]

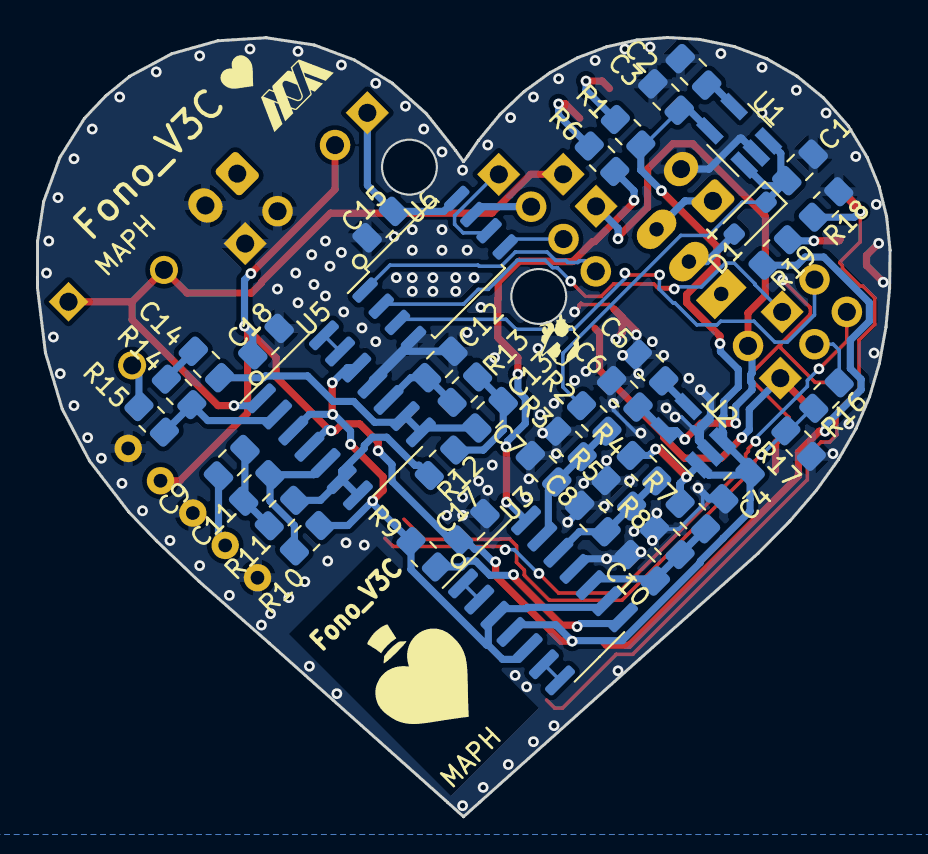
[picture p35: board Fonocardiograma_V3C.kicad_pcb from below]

Board: 2 copper layers, 47.4 x 43.3 mm, 60 parts (42 on the bottom side), 44 nets.

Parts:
C1, C4: 1uf; C_0805_2012Metric_Pad1.18x1.45mm_HandSolder
C2, C5: 100nf; C_0805_2012Metric_Pad1.18x1.45mm_HandSolder
C3, C6: 2.2uf; C_0805_2012Metric_Pad1.18x1.45mm_HandSolder
C7, C8, C10, C11: 470n; C_0805_2012Metric_Pad1.18x1.45mm_HandSolder
C9, C14: 2.2u; C_0805_2012Metric_Pad1.18x1.45mm_HandSolder
C12: 22n; C_0805_2012Metric_Pad1.18x1.45mm_HandSolder
C13, C15, C16, C17, C18: 100n; C_0805_2012Metric_Pad1.18x1.45mm_HandSolder
D1: 1N5819WS; D_SOD-323_HandSoldering
D2, D3, D4: LED; LED_0805_2012Metric_Pad1.15x1.40mm_HandSolder
J1, J9: Conn_01x02; JST_EH_S2B-EH_1x02_P2.50mm_Horizontal
J2, J7, J8: Conn_02x01; PinHeader_2x01_P2.54mm_Vertical
J3: Conn_01x04; PinHeader_1x04_P2.54mm_Vertical
J4, J5: Conn_01x01; PinHeader_1x01_P2.54mm_Vertical
J6: Conn_02x02_Odd_Even; PinHeader_2x02_P2.54mm_Vertical
R1, R6, R18, R19: 1k; R_0805_2012Metric_Pad1.20x1.40mm_HandSolder
R2, R4: 100K; R_0805_2012Metric_Pad1.20x1.40mm_HandSolder
R3: 51K; R_0805_2012Metric_Pad1.20x1.40mm_HandSolder
R5, R7: 75k; R_0805_2012Metric_Pad1.20x1.40mm_HandSolder
R8: 51k; R_0805_2012Metric_Pad1.20x1.40mm_HandSolder
R9: 50; R_0805_2012Metric_Pad1.20x1.40mm_HandSolder
R10: 15k; R_0805_2012Metric_Pad1.20x1.40mm_HandSolder
R11: 4.7k; R_0805_2012Metric_Pad1.20x1.40mm_HandSolder
R12: 1.2k; R_0805_2012Metric_Pad1.20x1.40mm_HandSolder
R13, R14, R15: 10k; R_0805_2012Metric_Pad1.20x1.40mm_HandSolder
R16: 100k; R_0805_2012Metric_Pad1.20x1.40mm_HandSolder
R17: 200k; R_0805_2012Metric_Pad1.20x1.40mm_HandSolder
RV1: 100k; Potentiometer_Runtron_RM-065_Vertical
SW1: SW_SPDT; SW_Slide_1P2T_SS12D00G4
SW2: SW_Push; BT_3x4x2h mm
U1: LP2985-5.0; SOT-23-5_HandSoldering
U2: LP2985-3.3; SOT-23-5_HandSoldering
U3, U5: LM324; SOIC-14_3.9x8.7mm_P1.27mm
U4: MAX9814; MAX9814-Adafruit
U6: ATtiny85-20S; SOP-8_5.28x5.23mm_P1.27mm
U7: HC-05; XCVR_HC-05

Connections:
2V Vref: R9.2, R10.2, U3.3 (+), U3.5 (+), U3.9 (-), U5.3 (+), U5.12 (+)
+3.3V: C6.1, J5.1, J8.2, SW2.2, U2.5 (VOUT)
+5V: C3.1, C4.1, C17.1, C18.1, J2.2, R1.1, R4.2, R7.2, U1.5 (VOUT), U2.1 (VIN), U2.3 (ON/~OFF), U3.4 (V+), U4.4 (VDD), U5.4 (V+)
+9V: C1.1, D1.1 (K), R2.2, U1.1 (VIN), U1.3 (ON/~OFF)
ADC1: J4.1, RV1.1, RV1.2, U5.1
GND: C1.2, C2.2, C3.2, C4.2, C5.2, C6.2, C7.1, C8.1, C10.1, C12.1, C15.1, C16.2, C17.2, C18.2, D2.1 (K), D3.1 (K), D4.1 (K), J1.2, J7.1, J7.2, J9.2, R3.1, R5.1, R8.1, R17.1, R18.2, U1.2 (GND), U2.2 (GND), U3.11 (V-), U4.1 (AR), U4.3 (GAIN), U4.5 (GND), U5.11 (V-), U6.4 (GND), U7.13 (GND), U7.21 (GND), U7.22 (GND)
MISO: J3.1, U6.6 (PB1)
MOSI/AREF: J3.3, U6.5 (AREF/PB0)
unnamed: C9.2, C11.1, R11.1
unnamed: C13.1, R12.2, R13.1
unnamed: C14.1, R14.2
unnamed: D1.2 (A), SW1.2 (B)
unnamed: D2.2 (A), R1.2
unnamed: D3.2 (A), R6.2
unnamed: D4.2 (A), R19.2
unnamed: J1.1, SW1.3 (C)
unnamed: C15.2, J2.1, U6.8 (VCC)
unnamed: C16.1, J8.1, U7.12 (3.3_VCC)
unnamed: R6.1, U3.14
unnamed: R9.1, U3.8
unnamed: R15.1, RV1.3
unnamed: C2.1, U1.4 (BP)
unnamed: C5.1, U2.4 (BP)
unnamed: U3.1, U3.2 (-)
unnamed: U3.6 (-), U3.7
unnamed: C10.2, R7.1, R8.2, U3.10 (+)
unnamed: C8.2, R4.1, R5.2, U3.12 (+)
unnamed: C7.2, R2.1, R3.2, U3.13 (-)
unnamed: C9.1, U4.2 (OUT)
unnamed: R14.1, R15.2, U5.2 (-)
unnamed: C11.2, R10.1, U5.5 (+)
unnamed: R11.2, R12.1, U5.6 (-), U5.7
unnamed: C12.2, R13.2, U5.10 (+)
unnamed: C13.2, C14.2, U5.8, U5.9 (-)
unnamed: U5.13 (-), U5.14
unnamed: R19.1, U7.31 (PIO[8])
unnamed: R18.1, SW2.1, U7.34 (PIO[11])
unnamed: R16.1, R17.2, U7.2 (UART-RX)
RESET: J3.4, U6.1 (~RESET/PB5)
RX: J6.3, U6.3 (XTAL2/PB4)
RXD: J6.2, R16.2
SCK/ADC1: J3.2, U6.7 (PB2)
TX: J6.1, U6.2 (XTAL1/PB3)
TXD: J6.4, U7.1 (UART-TX)

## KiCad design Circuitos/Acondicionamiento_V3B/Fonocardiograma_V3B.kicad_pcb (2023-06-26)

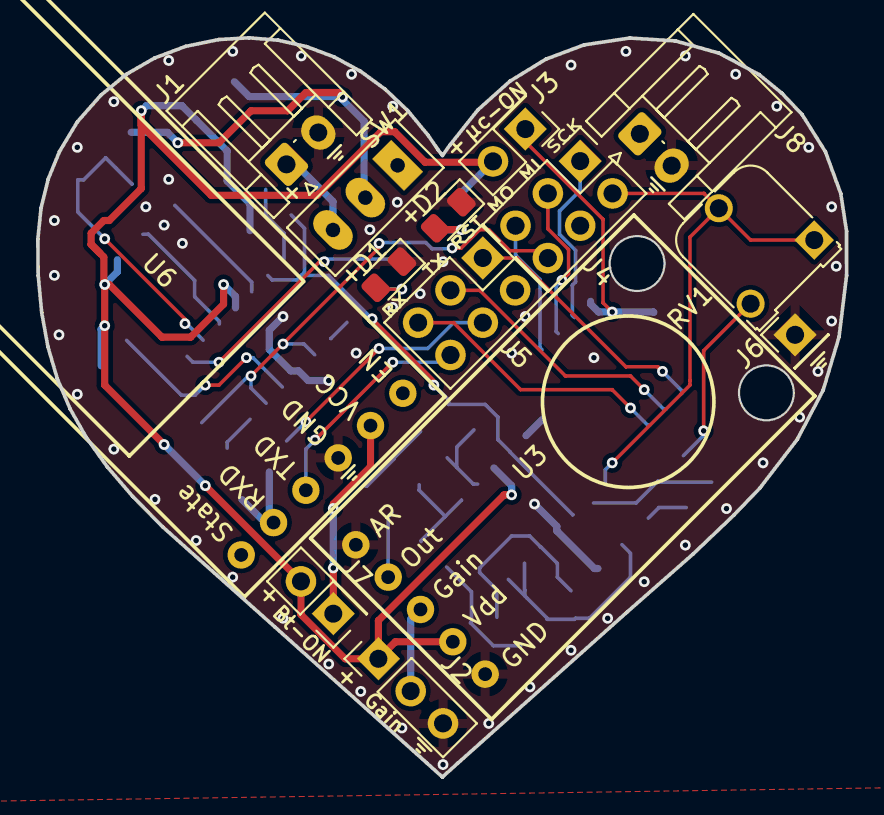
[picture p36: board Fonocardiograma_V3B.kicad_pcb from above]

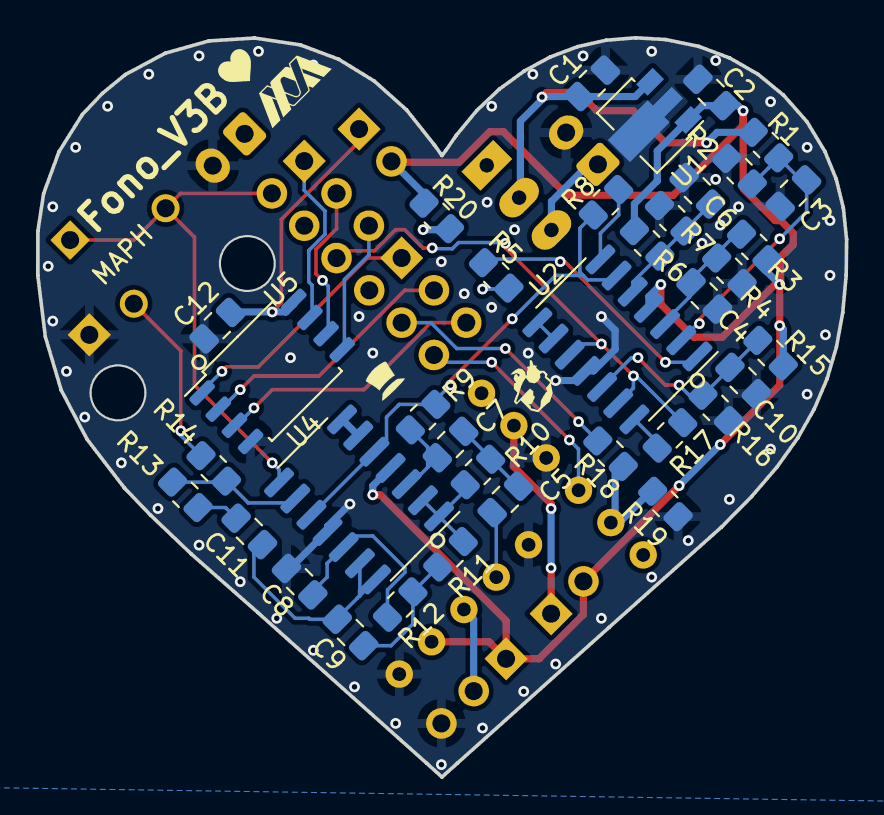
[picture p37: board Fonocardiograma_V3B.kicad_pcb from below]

Board: 2 copper layers, 44.9 x 41.1 mm, 50 parts (36 on the bottom side), 40 nets.

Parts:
C1: 330nf; C_0805_2012Metric_Pad1.18x1.45mm_HandSolder
C2: 100nf; C_0805_2012Metric_Pad1.18x1.45mm_HandSolder
C3, C4, C6, C7, C10: 470n; C_0805_2012Metric_Pad1.18x1.45mm_HandSolder
C5, C11: 2.2u; C_0805_2012Metric_Pad1.18x1.45mm_HandSolder
C8: 22n; C_0805_2012Metric_Pad1.18x1.45mm_HandSolder
C9, C12: 100n; C_0805_2012Metric_Pad1.18x1.45mm_HandSolder
D1, D2: LED; LED_0805_2012Metric_Pad1.15x1.40mm_HandSolder
J1, J8: Conn_01x02; JST_EH_S2B-EH_1x02_P2.50mm_Horizontal
J2: Conn_01x03; PinHeader_1x03_P2.54mm_Vertical
J3, J7: Conn_02x01; PinHeader_2x01_P2.54mm_Vertical
J4, J5: Conn_02x03_Odd_Even; PinHeader_2x03_P2.54mm_Vertical
J6: Conn_01x01; PinHeader_1x01_P2.54mm_Vertical
R1, R3, R4, R15: 100K; R_0805_2012Metric_Pad1.20x1.40mm_HandSolder
R2: 51K; R_0805_2012Metric_Pad1.20x1.40mm_HandSolder
R5, R20: 330; R_0805_2012Metric_Pad1.20x1.40mm_HandSolder
R6: 75k; R_0805_2012Metric_Pad1.20x1.40mm_HandSolder
R7: 51k; R_0805_2012Metric_Pad1.20x1.40mm_HandSolder
R8, R17: 50; R_0805_2012Metric_Pad1.20x1.40mm_HandSolder
R9: 15k; R_0805_2012Metric_Pad1.20x1.40mm_HandSolder
R10: 4.7k; R_0805_2012Metric_Pad1.20x1.40mm_HandSolder
R11: 1.2k; R_0805_2012Metric_Pad1.20x1.40mm_HandSolder
R12, R13, R14: 10k; R_0805_2012Metric_Pad1.20x1.40mm_HandSolder
R16: 200K; R_0805_2012Metric_Pad1.20x1.40mm_HandSolder
R18: 100k; R_0805_2012Metric_Pad1.20x1.40mm_HandSolder
R19: 200k; R_0805_2012Metric_Pad1.20x1.40mm_HandSolder
RV1: 100k; Potentiometer_Runtron_RM-065_Vertical
SW1: SW_SPDT; SW_Slide_1P2T_SS12D00G4
U1: L78L05_SOT89; SOT-89-3
U2, U4: LM324; SOIC-14_3.9x8.7mm_P1.27mm
U3: MAX9814; MAX9814-Adafruit
U5: ATtiny85-20S; SOP-8_5.28x5.23mm_P1.27mm
U6: HC-05

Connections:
2V Vref: R8.2, R9.2, U2.6 (-), U4.5 (+), U4.10 (+)
+5V: C2.1, J2.1, J3.2, J7.2, R3.2, R6.2, R15.2, R20.1, U1.1 (OUT), U2.4 (V+), U3.4 (VDD), U4.4 (V+)
+9V: C1.1, R1.2, SW1.2 (B), U1.3 (IN)
ADC1: J4.2, RV1.1, RV1.2, U4.8
AREF: J4.6, R17.2, U2.10 (+), U2.13 (-)
GAIN: J2.2, U3.3 (GAIN)
GND: C1.2, C2.2, C3.1, C4.1, C6.1, C8.1, C10.1, C12.1, D1.1 (K), D2.1 (K), J1.2, J2.3, J6.1, J8.2, R2.1, R4.1, R7.1, R16.1, R19.1, U1.2 (GND), U2.11 (V-), U3.1 (AR), U3.5 (GND), U4.11 (V-), U5.4 (GND), U6.4 (GND)
MISO: J4.3, U5.6 (PB1)
MOSI/AREF: J4.5, U5.5 (AREF/PB0)
unnamed: C12.2, J3.1, U5.8 (VCC)
unnamed: J7.1, U6.5 (VCC)
unnamed: C5.2, C7.1, R10.1
unnamed: C9.1, R11.2, R12.1
unnamed: C11.1, R13.2
unnamed: D1.2 (A), R5.2
unnamed: D2.2 (A), R20.2
unnamed: J1.1, SW1.3 (C)
unnamed: R5.1, U2.1
unnamed: R8.1, U2.7
unnamed: R14.1, RV1.3
unnamed: R17.1, U2.14
unnamed: C4.2, R3.1, R4.2, U2.3 (+)
unnamed: C3.2, R1.1, R2.2, U2.2 (-)
unnamed: C6.2, R6.1, R7.2, U2.5 (+)
unnamed: U2.8, U2.9 (-)
unnamed: C10.2, R15.1, R16.2, U2.12 (+)
unnamed: C5.1, U3.2 (OUT)
unnamed: C7.2, R9.1, U4.3 (+)
unnamed: R10.2, R11.1, U4.1, U4.2 (-)
unnamed: U4.6 (-), U4.7
unnamed: R13.1, R14.2, U4.9 (-)
unnamed: C8.2, R12.2, U4.12 (+)
unnamed: C9.2, C11.2, U4.13 (-), U4.14
unnamed: R18.2, R19.2, U6.2 (RXD)
RESET: J5.1, U5.1 (~RESET/PB5)
RX: J5.5, U5.3 (XTAL2/PB4)
RXD: J5.4, R18.1
SCK/ADC1: J4.1, U5.7 (PB2)
TX: J5.3, U5.2 (XTAL1/PB3)
TXD: J5.6, U6.3 (TXD)

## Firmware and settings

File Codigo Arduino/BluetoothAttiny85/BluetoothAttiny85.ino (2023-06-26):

#include <SoftwareSerial.h>   // Incluimos la librerÃ­a  SoftwareSerial  
#define pinTX 3
#define pinRX 4
#define  PIN_VOUT A1
SoftwareSerial BT(pinRX,pinTX);    // Definimos los pines RX y TX del Arduino conectados al Bluetooth


// Lee del puerto serial 'a' para iniciar el envio de datos y 'b' para detenerlo
#define  CASO_INICIO   'a'
#define  CASO_DETENER  'b'

int leido = 0;
bool envia_datos = false;

void setup() {
  BT.begin(38400);       
  analogReference(EXTERNAL);
}

// Envia el dato de forma binaria 
// 'a'-> CASO INICIO
// 'b'-> CASO DETENER


void loop() {  
  if(BT.available()){
    leido = BT.read();
    
    if(leido == CASO_INICIO)
      envia_datos = true;
    
    if(leido == CASO_DETENER)
      envia_datos = false;
  }
 
  if(envia_datos){
      i = analogRead(PIN_VOUT);
      BT.write(highByte(i));
      BT.write(lowByte(i));
  }
}

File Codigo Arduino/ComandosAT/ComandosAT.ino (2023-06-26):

#include <SoftwareSerial.h>  
SoftwareSerial BT(10,11);   // Pin TX y RX del fono
 
void setup(){
  BT.begin(38400);          // Inicializacion del puerto Serie BT
  Serial.begin(38400);      // Inicializacion del puerto Serie
}
 
void loop(){
  if(BT.available()){       // Si llega un dato por el puerto BT se envía al monitor serial
    Serial.write(BT.read());
  }
 
  if(Serial.available()){   // Si llega un dato por el monitor serial se envía al puerto BT
     BT.write(Serial.read());
  }
}

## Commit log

2023-06-26 Add Files
    *Circuitos
    *Codigo AndroidStudio
    *Codigo Arduino
    [Fonocardiograma_V3A-B_Cu.gbl, Fonocardiograma_V3A-B_Mask.gbs, Fonocardiograma_V3A-B_Paste.gbp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]
2023-06-26 Basura quitada
    [Fonocardiograma_V3A.kicad_sch, Fonocardiograma_V3B.kicad_sch]
2023-06-28 Reporte
    Correccion de errores y reporte
2023-06-29 Final
    Push final de PT, bye bye hasta la proxima
2023-06-30 BaudRate LAN
    BaudRate LAN y correción de errores
